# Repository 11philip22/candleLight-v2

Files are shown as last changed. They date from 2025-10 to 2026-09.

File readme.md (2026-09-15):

# candleLight USB-to-CAN Adapter

A KiCad **USB-to-CAN adapter** built around the **STM32F072** microcontroller and **TJA1051TK-3** CAN transceiver. USB-C connects to the host, while a screw terminal exposes CAN_H, CAN_L, and GND. The board includes selectable 120 Ω CAN termination and headers for SWD, USART, and SPI.

| Top — USB connector side | Bottom — through-hole models hidden |
| :---: | :---: |
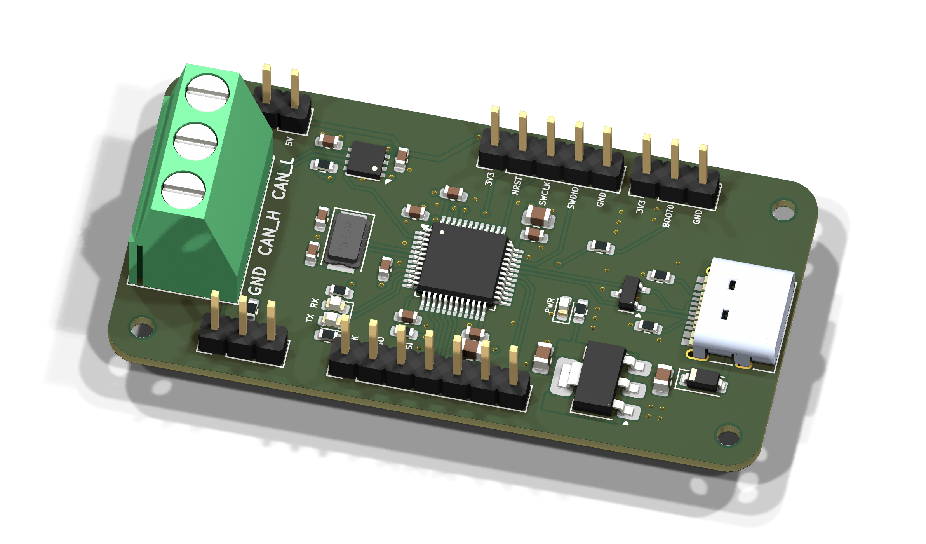
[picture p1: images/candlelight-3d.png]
Top 3D view of the candleLight USB-to-CAN adapter
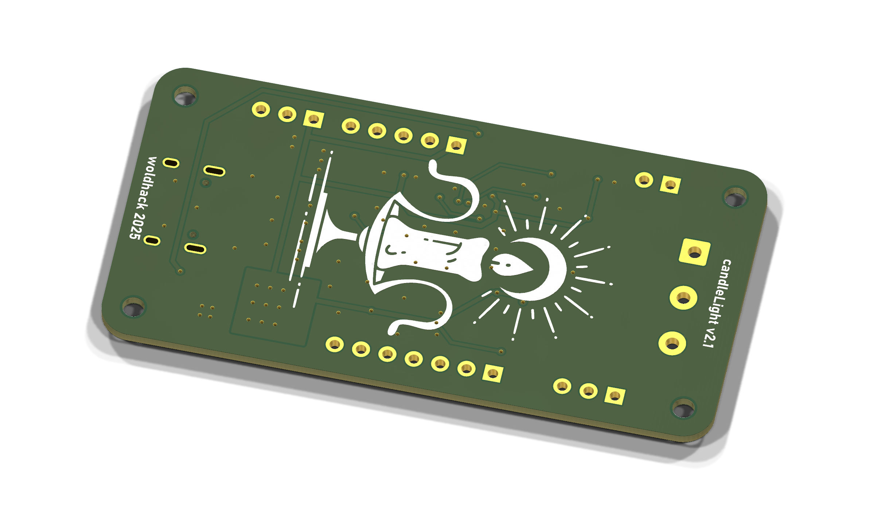
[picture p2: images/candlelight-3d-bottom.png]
Bottom 3D view with through-hole component models hidden
|  |  |

## Project files

| File | Description |
| --- | --- |
| [candleLight.kicad_pro](candleLight.kicad_pro) | KiCad project |
| [candleLight.kicad_sch](candleLight.kicad_sch) | Schematic |
| [candleLight.kicad_pcb](candleLight.kicad_pcb) | Two-layer PCB, revision V2.1, 1.2 mm thick |
| [lib/](lib/) | Custom symbols, footprints, and 3D models (Git submodule) |
| [production/](production/) | Fabrication archive, bill of materials, component positions, and netlist |

## Open in KiCad

Initialize the library submodule before opening the project:

```sh
git submodule update --init --recursive
```

Open `candleLight.kicad_pro` in KiCad 9 or newer, with the standard symbol, footprint, and 3D-model libraries installed. The board references `KICAD9_3DMODEL_DIR`; when using a newer KiCad version, set that path variable to the installed 3D-model library directory if models are missing.

## Board revisions

### [V2.1](https://github.com/11philip22/candleLight-v2/tree/v2.1)

- Reworked decoupling capacitors.
- Added NRST and BOOT0 controls, an NRST pull-up, and a higher-value BOOT0 resistor.
- Added selectable CAN termination and a BOOT0 selection header.
- Changed the crystal to a JLCPCB basic part.
- Improved the SWD header and added USART and SPI headers.
- Upgraded the CAN transceiver from TJA1051-3 to TJA1051TK-3.
- Added a Schottky diode between VBUS and V5+ and ESD protection on the USB lines.

### [V2](https://github.com/11philip22/candleLight-v2/tree/v2)

- Changed the voltage regulator and crystal.
- Switched to USB-C.
- Replaced the Tag-Connect connector with standard pin headers.
- Replaced the VGA-style CAN connector with a Phoenix screw terminal.

## Board photos

### [V2.1](https://github.com/11philip22/candleLight-v2/tree/v2.1)

| Assembly photo 1 | Assembly photo 2 | Assembly photo 3 |
| :---: | :---: | :---: |
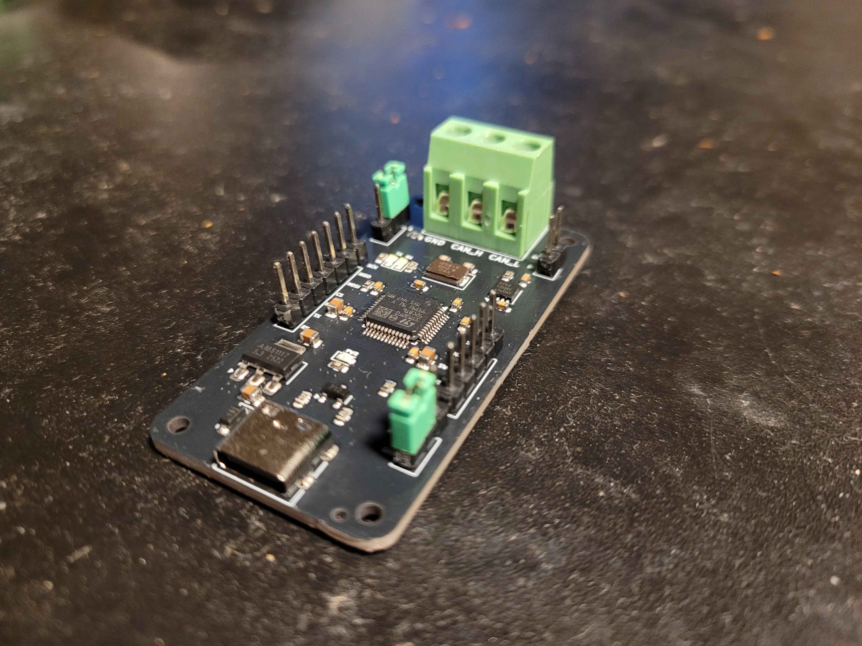
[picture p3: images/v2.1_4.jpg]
candleLight V2.1 assembly photo 1
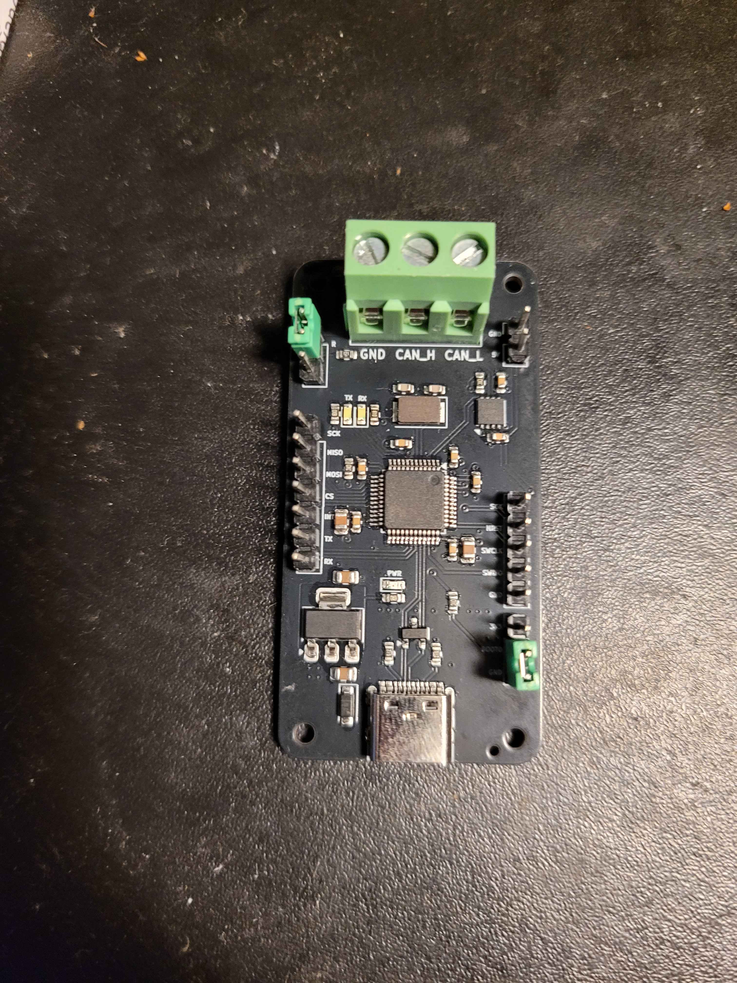
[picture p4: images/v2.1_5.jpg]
candleLight V2.1 assembly photo 2
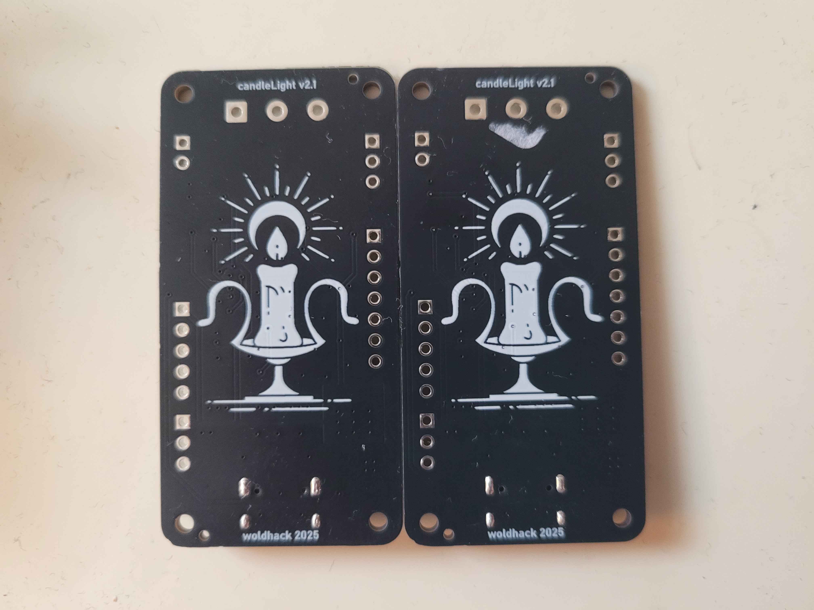
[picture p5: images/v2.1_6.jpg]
candleLight V2.1 assembly photo 3
| [](images/v2.1_4.jpg) | [](images/v2.1_5.jpg) | [](images/v2.1_6.jpg) |

### [V2](https://github.com/11philip22/candleLight-v2/tree/v2)

| Assembly photo 1 | Assembly photo 2 | Assembly photo 3 |
| :---: | :---: | :---: |
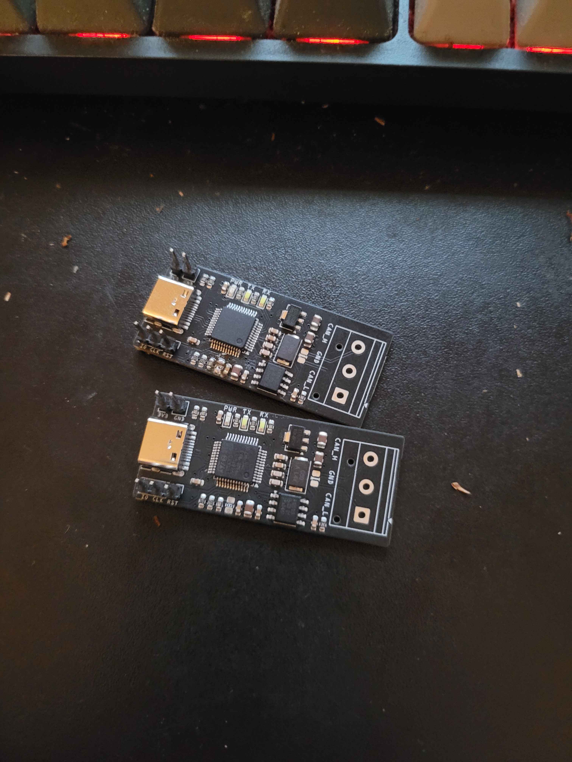
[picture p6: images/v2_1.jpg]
candleLight V2 assembly photo 1
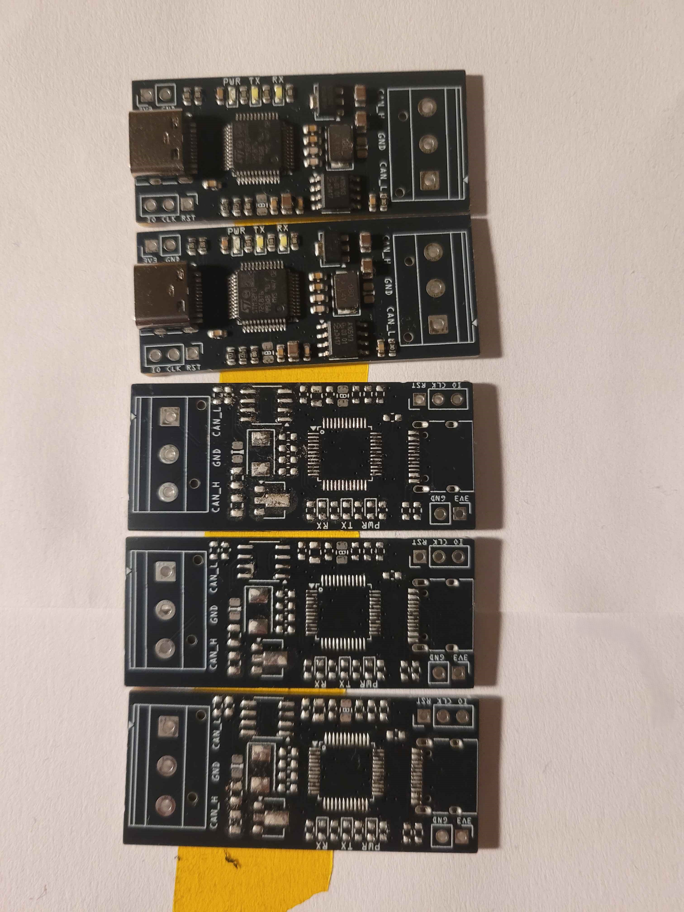
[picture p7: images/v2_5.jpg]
candleLight V2 assembly photo 2
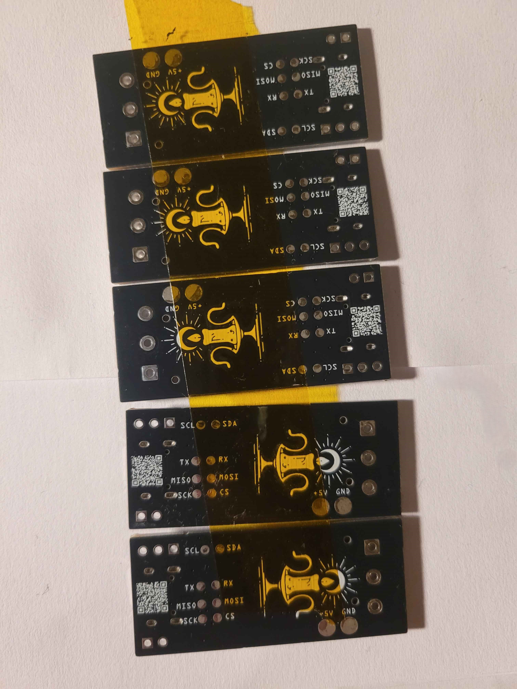
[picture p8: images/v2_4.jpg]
candleLight V2 assembly photo 3
| [](images/v2_1.jpg) | [](images/v2_5.jpg) | [](images/v2_4.jpg) |

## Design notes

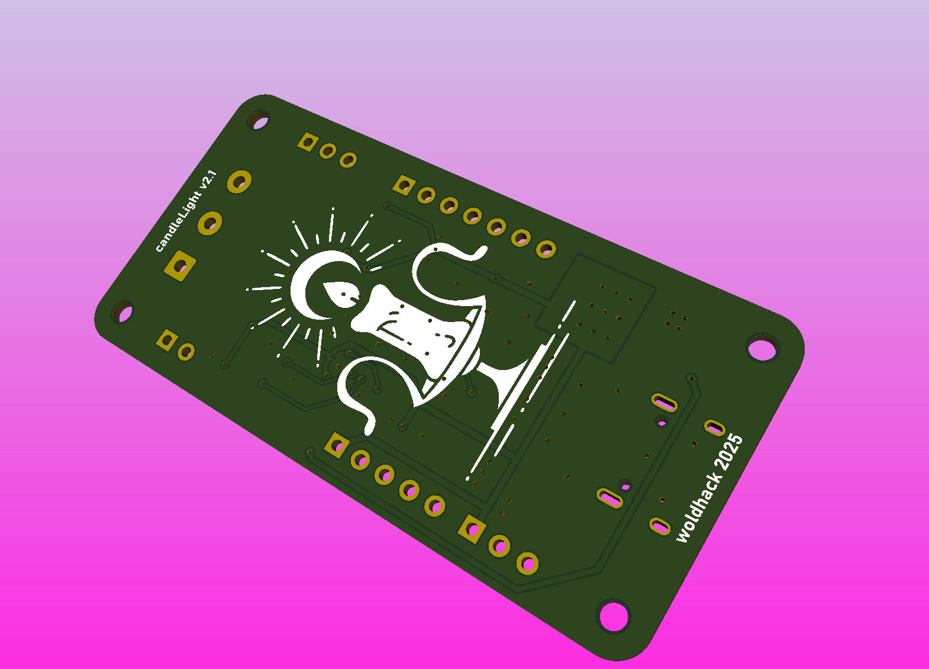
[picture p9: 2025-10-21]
images/v2.1_3.png

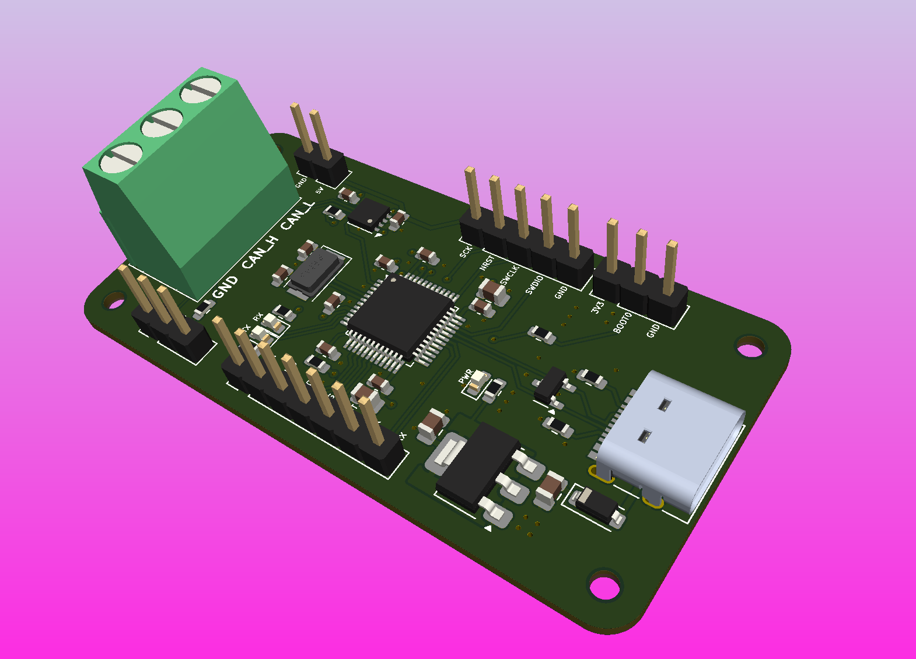
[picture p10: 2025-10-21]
images/v2.1_1.png

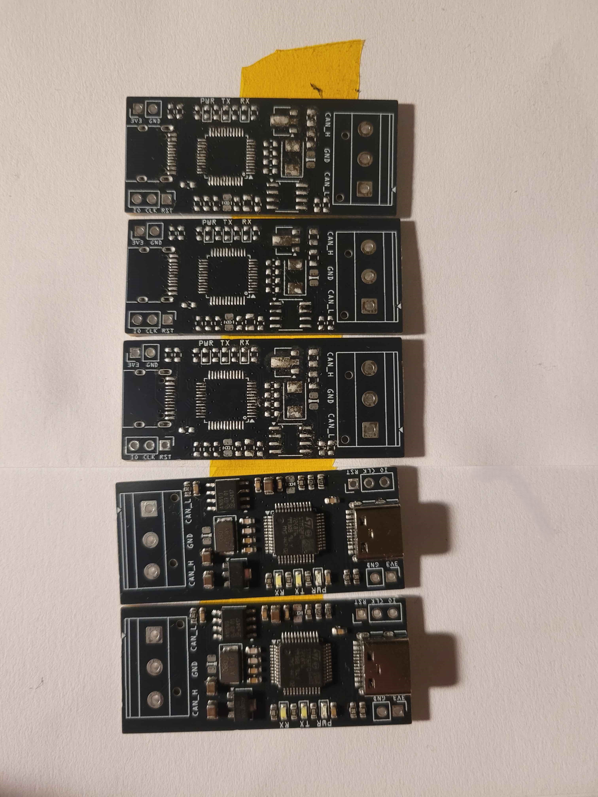
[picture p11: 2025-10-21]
images/v2_2.jpg

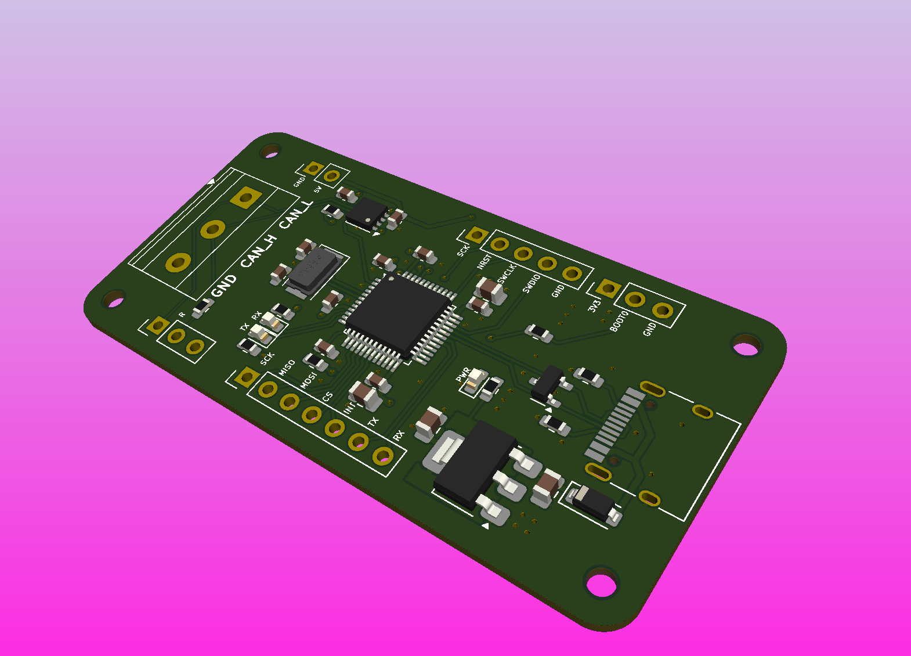
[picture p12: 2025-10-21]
images/v2.1_2.png

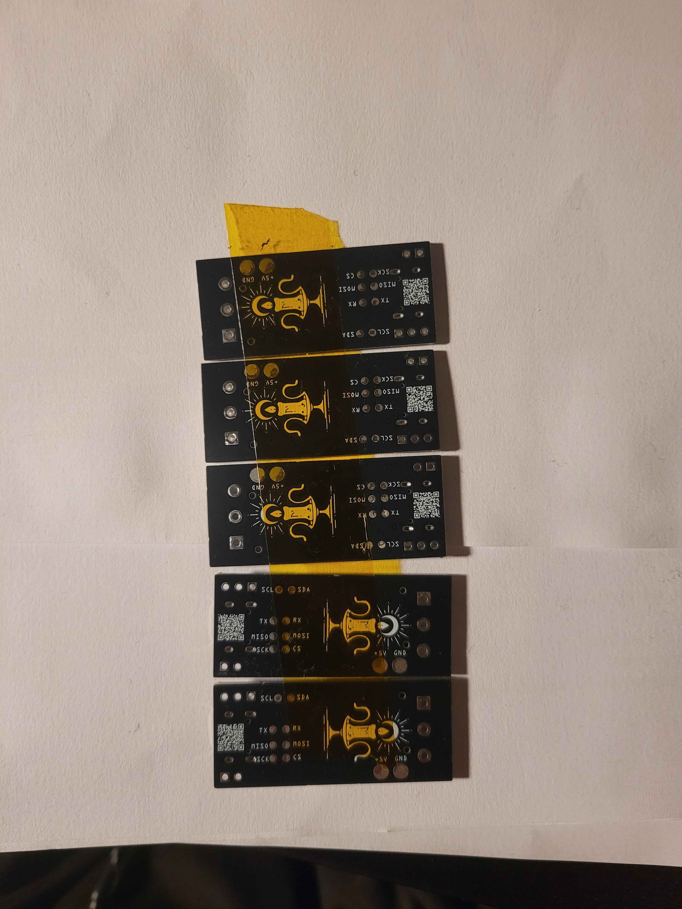
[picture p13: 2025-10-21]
images/v2_3.jpg

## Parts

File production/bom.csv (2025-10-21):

Designator | Footprint | Quantity | Value | LCSC Part #
C1, C2 | 0603 | 2 | 30pF | C1658
C10, C12, C13, C3, C6, C7, C8, C9 | 0603 | 8 | 100nF | C14663
C11, C14, C4, C5 | 0805 | 4 | 10uF | C15850
D1, D2 | 0603 | 2 | LED | C2290
D3 | 0603 | 1 | LED | C2286
D4 | SOT-23 | 1 | PSM712 | C32677
D5 | D_SOD-123 | 1 | ~ | C8598
J1 | USB_C_Receptacle_HRO_TYPE-C-31-M-12 | 1 | USB_C_Receptacle_USB2.0 | C165948
J2 | TerminalBlock_Phoenix_MKDS-1,5-3-5.08_1x03_P5.08mm_Horizontal | 1 | Conn_Phoenix | C474951
J3 | PinHeader_1x05_P2.54mm_Vertical | 1 | Conn_SWD | C32713271
J4 | PinHeader_1x07_P2.54mm_Vertical | 1 | Conn_IO | C32713273
J5 | PinHeader_1x03_P2.54mm_Vertical | 1 | Conn_BOOT0 | C32713269
J6 | PinHeader_1x03_P2.54mm_Vertical | 1 | Conn_CAN_Jumper | C32713269
J7 | PinHeader_1x02_P2.54mm_Vertical | 1 | Conn_5V | C32713268
R1, R2 | 0603 | 2 | 5k1 | C23186
R3, R4, R5 | 0603 | 3 | 10K | C25804
R6 | 0603 | 1 | 120 | C22787
R7, R8, R9 | 0603 | 3 | 1K | C21190
U1 | LQFP-48_7x7mm_P0.5mm | 1 | STM32F072C8Tx | C80488
U2 | SOT-223-3_TabPin2 | 1 | AMS1117-3.3 | C6186
U3 | DFN-8-1EP_3x3mm_P0.65mm_EP1.55x2.4mm | 1 | TJA1051TK-3 | C2875699
Y1 | Crystal_SMD_Abracon_ABM3-2Pin_5.0x3.2mm | 1 | 8MHz | C115962

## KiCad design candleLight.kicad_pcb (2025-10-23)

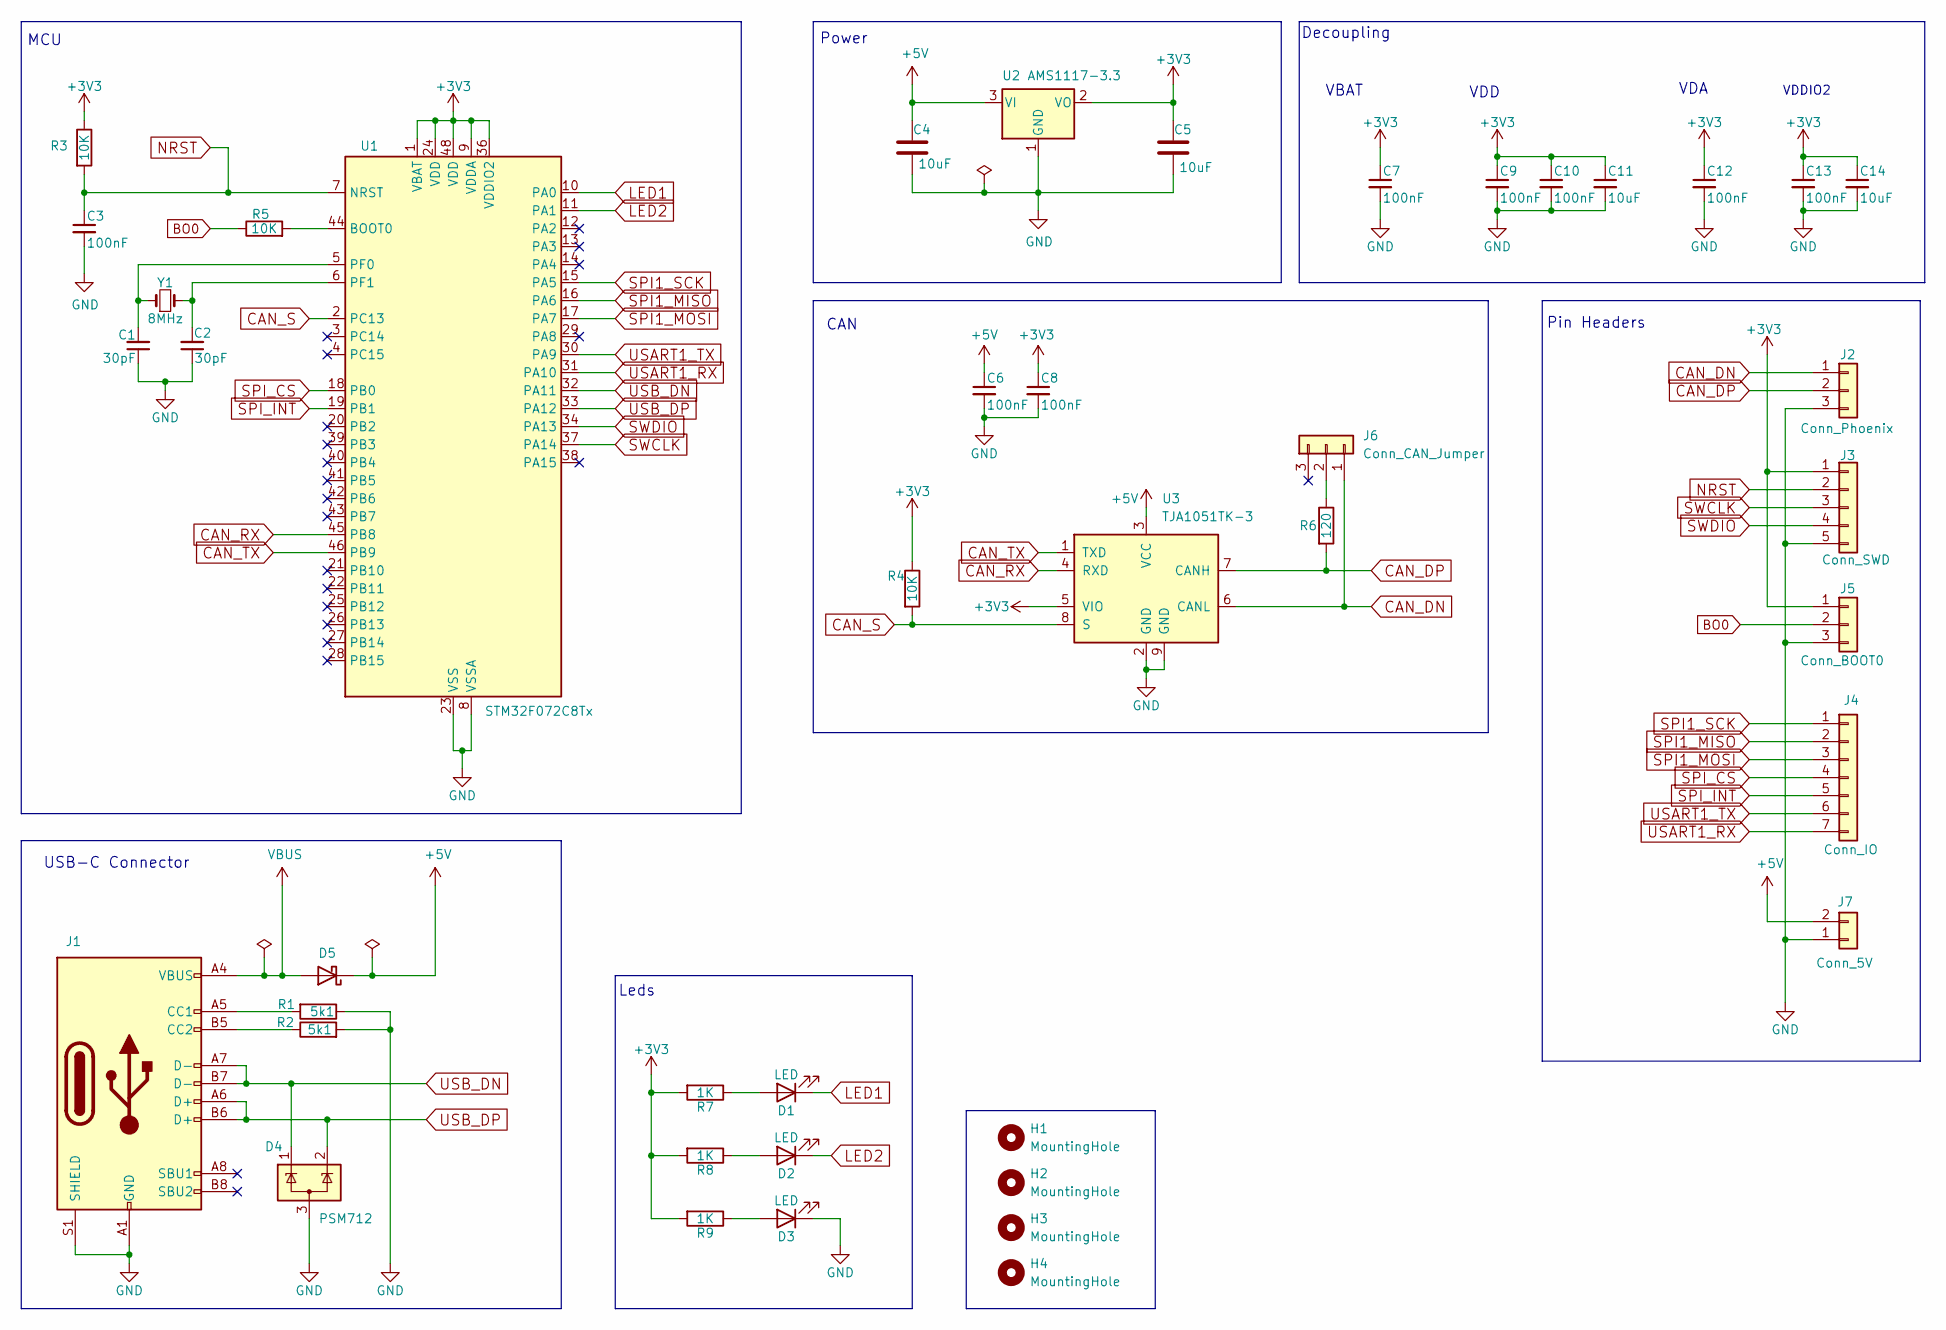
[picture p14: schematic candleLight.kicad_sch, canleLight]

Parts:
C1, C2: 30pF; C_0603_1608Metric; LCSC C1658
C3, C6, C7, C8, C9, C10, C12, C13: 100nF; C_0603_1608Metric; LCSC C14663
C4, C5, C11, C14: 10uF; C_0805_2012Metric; LCSC C15850
D1, D2: LED; LED_0603_1608Metric; LCSC C2290
D3: LED; LED_0603_1608Metric; LCSC C2286
D4: PSM712; SOT-23; LCSC C32677
D5: D_SOD-123; LCSC C8598
H1, H2, H3, H4: MountingHole; MountingHole_2.1mm
J1: USB_C_Receptacle_USB2.0; USB_C_Receptacle_HRO_TYPE-C-31-M-12; LCSC C165948
J2: Conn_Phoenix; TerminalBlock_Phoenix_MKDS-1,5-3-5.08_1x03_P5.08mm_Horizont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; LCSC C474951
J3: Conn_SWD; PinHeader_1x05_P2.54mm_Vertical; LCSC C32713271
J4: Conn_IO; PinHeader_1x07_P2.54mm_Vertical; LCSC C32713273
J5: Conn_BOOT0; PinHeader_1x03_P2.54mm_Vertical; LCSC C32713269
J6: Conn_CAN_Jumper; PinHeader_1x03_P2.54mm_Vertical; LCSC C32713269
J7: Conn_5V; PinHeader_1x02_P2.54mm_Vertical; LCSC C32713268
R1, R2: 5k1; R_0603_1608Metric; LCSC C23186
R3, R4, R5: 10K; R_0603_1608Metric; LCSC C25804
R6: 120; R_0603_1608Metric; LCSC C22787
R7, R8, R9: 1K; R_0603_1608Metric; LCSC C21190
U1: STM32F072C8Tx; LQFP-48_7x7mm_P0.5mm; LCSC C80488
U2: AMS1117-3.3; SOT-223-3_TabPin2; LCSC C6186
U3: TJA1051TK-3; DFN-8-1EP_3x3mm_P0.65mm_EP1.55x2.4mm; LCSC C2875699
Y1: 8MHz; Crystal_SMD_Abracon_ABM3-2Pin_5.0x3.2mm; LCSC C115962

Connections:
+3V3: C5.1, C7.1, C8.1, C9.1, C10.1, C11.1, C12.1, C13.1, C14.1, J3.1, J5.1, R3.1, R4.1, R7.2, R8.2, R9.2, U1.1 (VBAT), U1.9 (VDDA), U1.24 (VDD), U1.36 (VDDIO2), U1.48 (VDD), U2.2 (VO), U3.5 (VIO)
+5V: C4.1, C6.1, D5.1 (K), J7.2 (Pin_1), U2.3 (VI), U3.3 (VCC)
BO0: J5.2, R5.1
CAN_DN: J2.1, J6.1 (Pin_3), U3.6 (CANL)
CAN_DP: J2.2, R6.2, U3.7 (CANH)
CAN_RX: U1.45 (PB8), U3.4 (RXD)
CAN_S: R4.2, U1.2 (PC13), U3.8 (S)
CAN_TX: U1.46 (PB9), U3.1 (TXD)
GND: C1.1, C2.1, C3.2, C4.2, C5.2, C6.2, C7.2, C8.2, C9.2, C10.2, C11.2, C12.2, C13.2, C14.2, D3.1 (K), D4.3 (A), J1.A1 (GND), J1.A12 (GND), J1.B1 (GND), J1.B12 (GND), J1.S1 (SHIELD), J2.3, J3.5, J5.3, J7.1 (Pin_2), R1.1, R2.2, U1.8 (VSSA), U1.23 (VSS), U1.35 (VSS), U1.47 (VSS), U2.1 (GND), U3.2 (GND), U3.9 (GND)
LED1: D1.1 (K), U1.10 (PA0)
LED2: D2.1 (K), U1.11 (PA1)
NRST: C3.1, J3.2, R3.2, U1.7 (NRST)
unnamed: D1.2 (A), R7.1
unnamed: D2.2 (A), R8.1
unnamed: D3.2 (A), R9.1
unnamed: J1.A5 (CC1), R1.2
unnamed: J1.B5 (CC2), R2.1
unnamed: J6.2, R6.1
unnamed: R5.2, U1.44 (BOOT0)
unnamed: C1.2, U1.5 (PF0), Y1.1
unnamed: C2.2, U1.6 (PF1), Y1.2
SPI1_MISO: J4.2, U1.16 (PA6)
SPI1_MOSI: J4.3, U1.17 (PA7)
SPI1_SCK: J4.1, U1.15 (PA5)
SPI_CS: J4.4, U1.18 (PB0)
SPI_INT: J4.5, U1.19 (PB1)
SWCLK: J3.3, U1.37 (PA14)
SWDIO: J3.4, U1.34 (PA13)
USART1_RX: J4.7, U1.31 (PA10)
USART1_TX: J4.6, U1.30 (PA9)
USB_DN: D4.1 (K), J1.A7 (D-), J1.B7 (D-), U1.32 (PA11)
USB_DP: D4.2 (K), J1.A6 (D+), J1.B6 (D+), U1.33 (PA12)
VBUS: D5.2 (A), J1.A4 (VBUS), J1.A9 (VBUS), J1.B4 (VBUS), J1.B9 (VBUS)

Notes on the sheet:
MCU
Leds
VDD
USB-C Connector
VDDIO2
VBAT
VDA
Power
Pin Headers
CAN
Decoupling

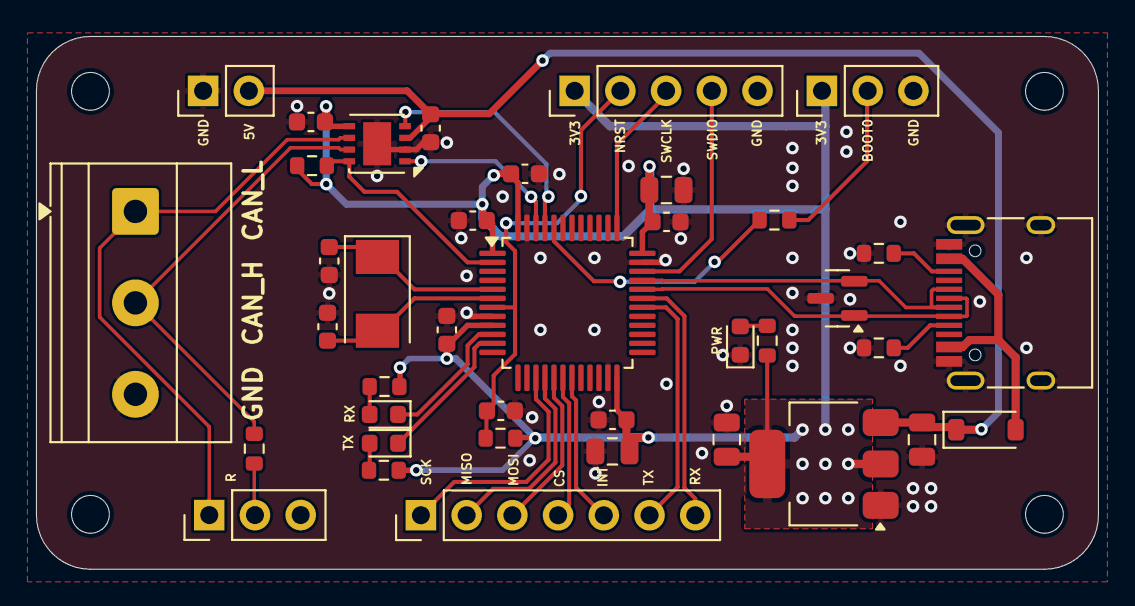
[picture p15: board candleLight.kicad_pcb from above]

Board: 2 copper layers, 59.0 x 29.6 mm, 43 parts (0 on the bottom side), 33 nets.

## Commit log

2025-10-03 kicad 9
    [CAN-2025-09-30-22-25-43.sch, CAN.kicad_sch, CAN.sch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]
2025-10-04 remove eagle files
    [CAN.sch, candleLight.sch, connectors.sch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]
2025-10-07 v2 ready
    [bom.csv, candleLight-v1.1.xls, candleLight.kicad_pcb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]
2025-10-07 production :)
    [bom.csv, candleLight.kicad_pcb, candleLight.kicad_sch]
2025-10-11 update schematic
    [candleLight.kicad_pcb, candleLight.kicad_sch]
2025-10-11 lib submodule
    [candleLight.kicad_pcb]
2025-10-17 inital board
    [candleLight.kicad_pcb, candleLight.kicad_sch]
2025-10-20 update silkscreen
    [CAN.kicad_sch, candleLight.kicad_pcb, candleLight.kicad_sch]
2025-10-21 uppdate silkscreen and SPI header
    [bom.csv, candleLight.kicad_pcb, candleLight.kicad_sch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]
2025-10-21 update load caps
    [candleLight.kicad_pcb, candleLight.kicad_sch]
2025-10-21 add datasheet
    [candleLight.kicad_pcb, candleLight.kicad_sch]
2025-10-23 fix silkscreen
    [candleLight.kicad_pcb]
